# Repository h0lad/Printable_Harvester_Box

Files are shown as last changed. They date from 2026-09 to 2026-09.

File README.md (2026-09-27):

## What is this thing?

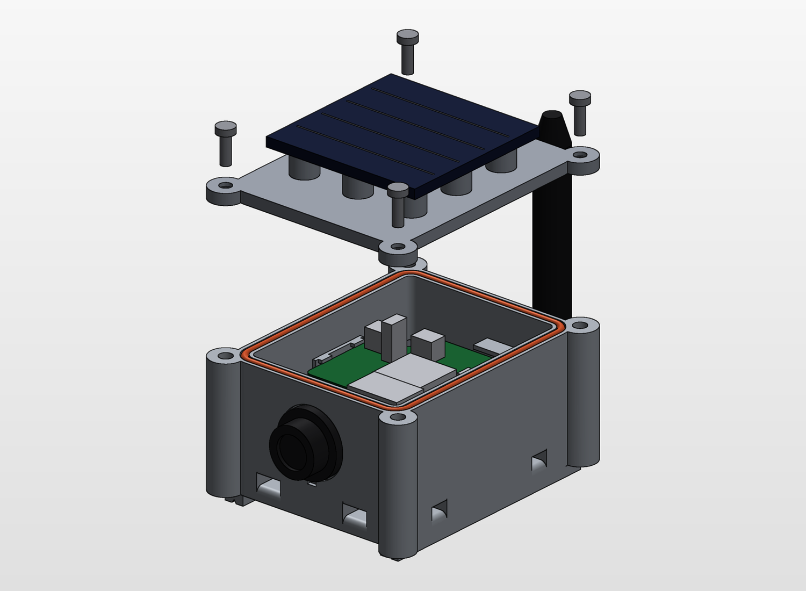
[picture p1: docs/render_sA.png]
An exploded view: the lid and its solar panel lifted off the base, with the O-ring cord and the PCB in place

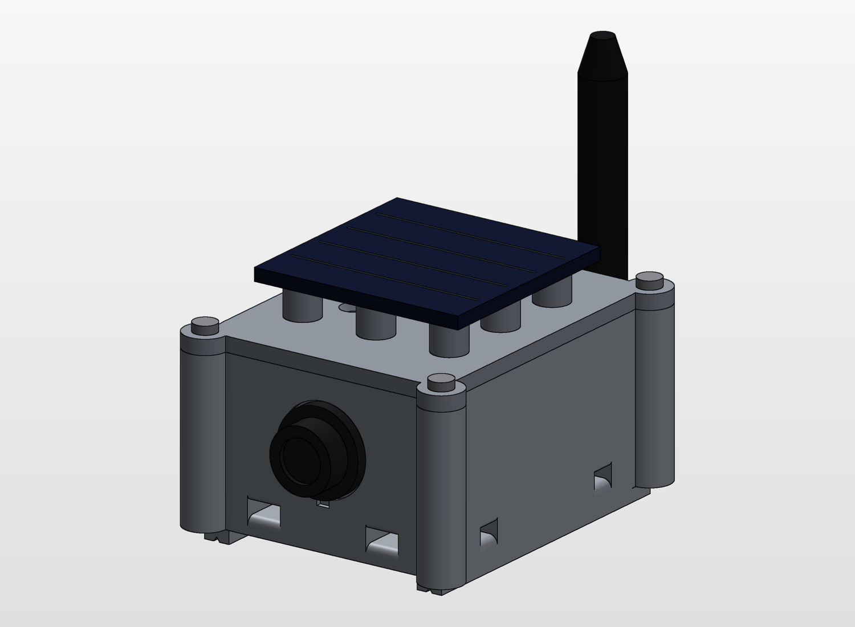
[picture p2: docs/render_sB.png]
The assembled box, with the SMA bulkhead in the front wall and the antenna standing above it

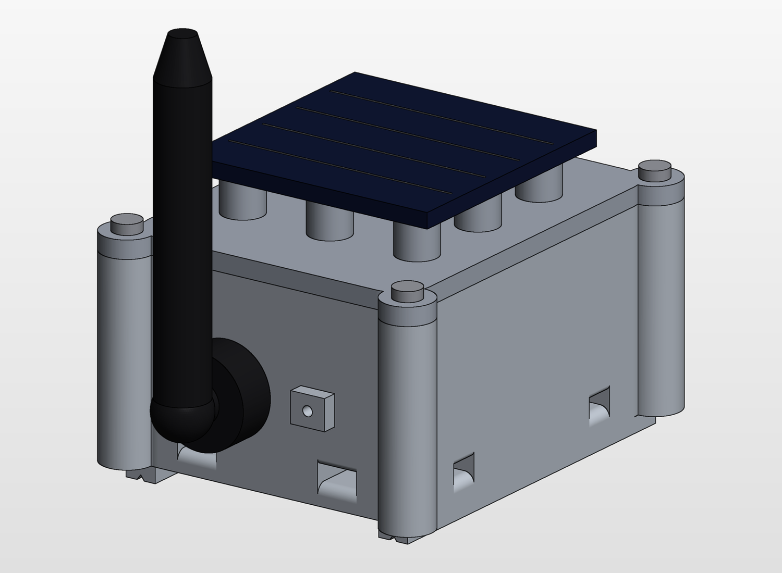
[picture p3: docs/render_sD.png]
The assembled box seen from the antenna corner, with the vent plug in the side wall


This box holds a PicoLoRaHarvester or a LoRaHarvesterbox.

## Dimensions

The body is 73.2 x 58.2 x 41.5 mm. It measures 83 x 68 mm over the screw columns and 44.5 mm over the
skids.

Two skids of 6 x 3 mm run under the floor, and each one carries a 3 x 1 mm V-groove in its face.

The inner cavity is 64 x 49 x 29 mm, and the vent chamber occupies x 56 to 64.

## Material

Bright nylon, printed by SLS or MJF. One material that JLC3DP stocks is 3301PA nylon, printed by SLS.

Don't even think of using PLA...

## Components to buy

- LiPo 852040, up to 45 mm including the protection board, with a JST-PH lead
- SMA bulkhead to U.FL pigtail, inner nose up to 20 mm, with its O-ring and at least 90 mm of cable
- Solar panel, 50 x 50 mm, bonded with epoxy or MS polymer
- ePTFE vent plug, thread 12 mm diameter and 10 mm long, head up to 20 mm, with its plastic nut
- 2 mm silicone O-ring cord, about 250 mm
- 4 M3x8 A4 screws, 1 M2x5 screw, and 4 M3 heat set inserts
- Cable ties of 5 x 1.5 mm, or cord up to 3 mm, for the lashing tunnels

## License

CERN Open Hardware Licence Version 2 - Strongly Reciprocal

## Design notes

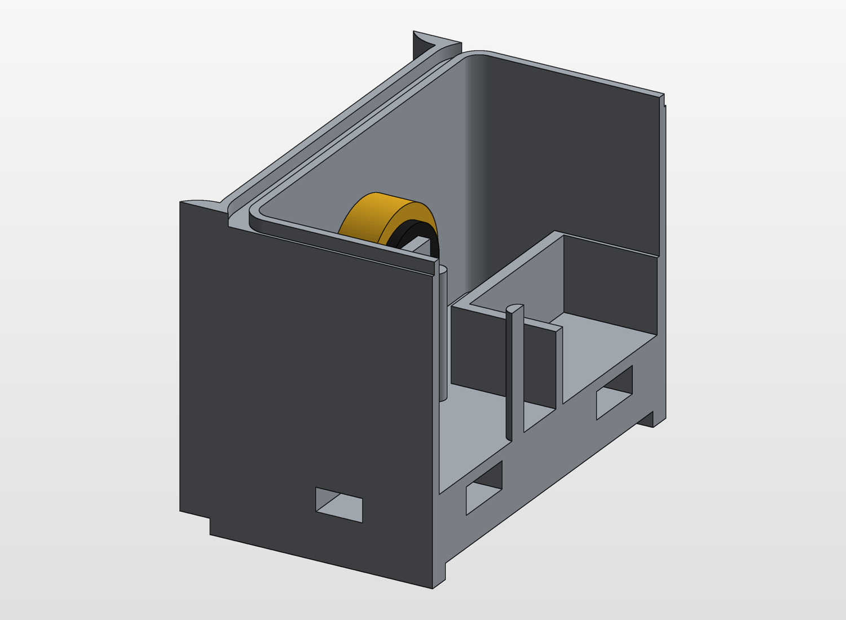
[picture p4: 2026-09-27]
docs/render_sF.png

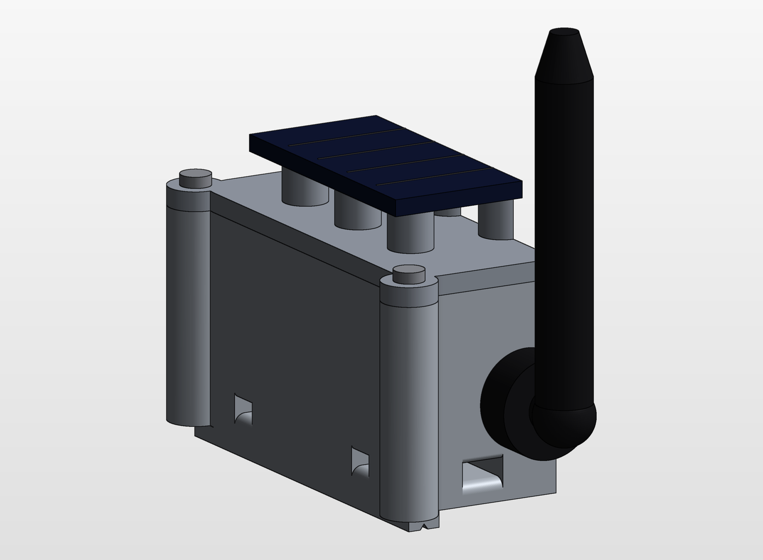
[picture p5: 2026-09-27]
docs/render_sE.png

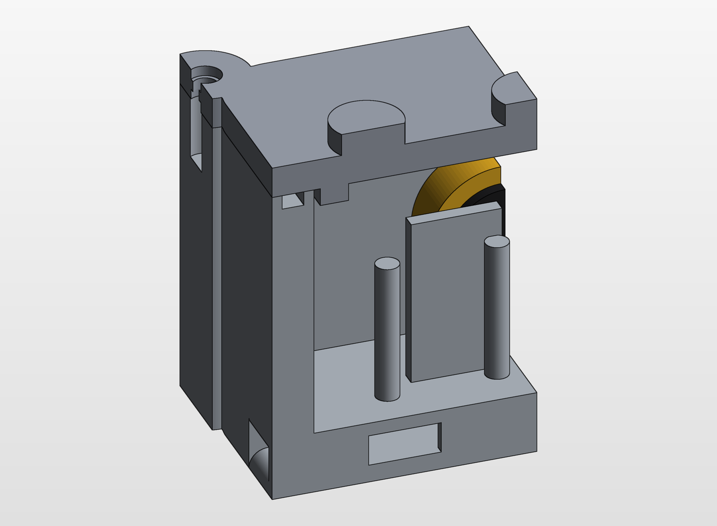
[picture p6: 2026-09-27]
docs/render_sG.png

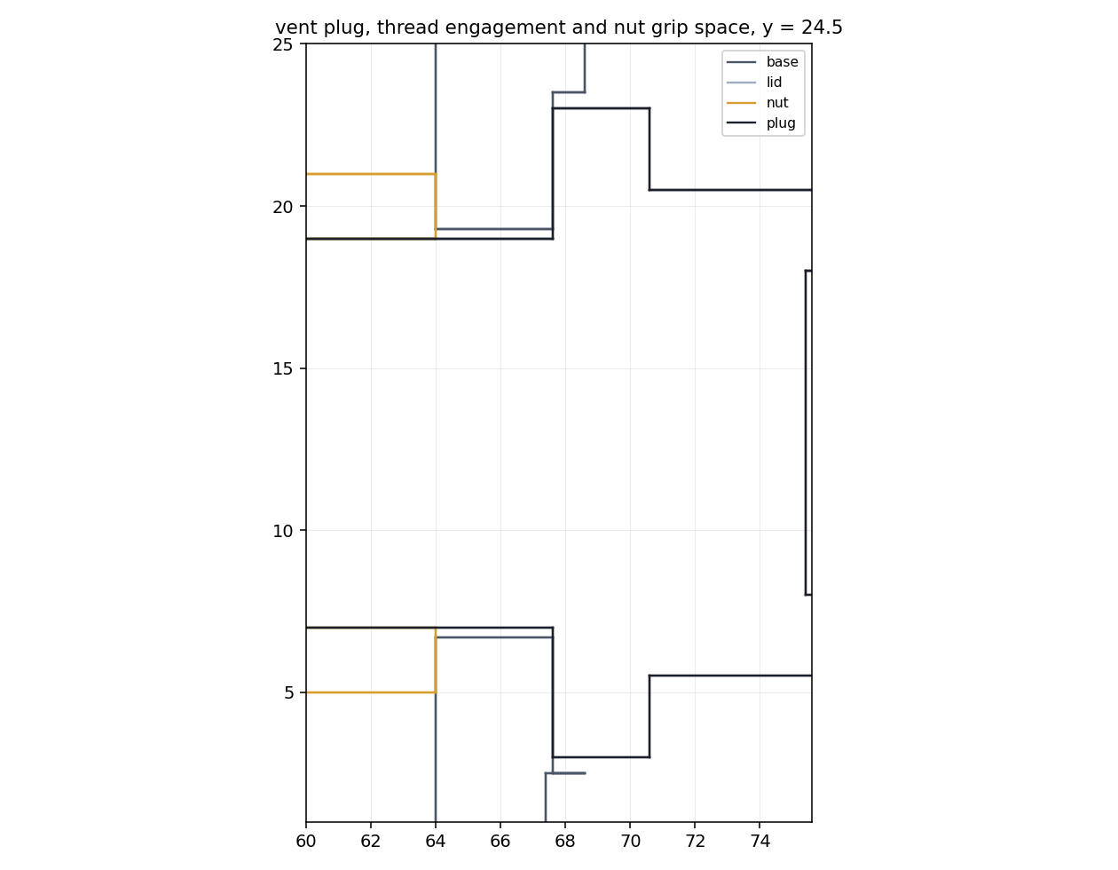
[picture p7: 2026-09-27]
docs/vent_detail.png

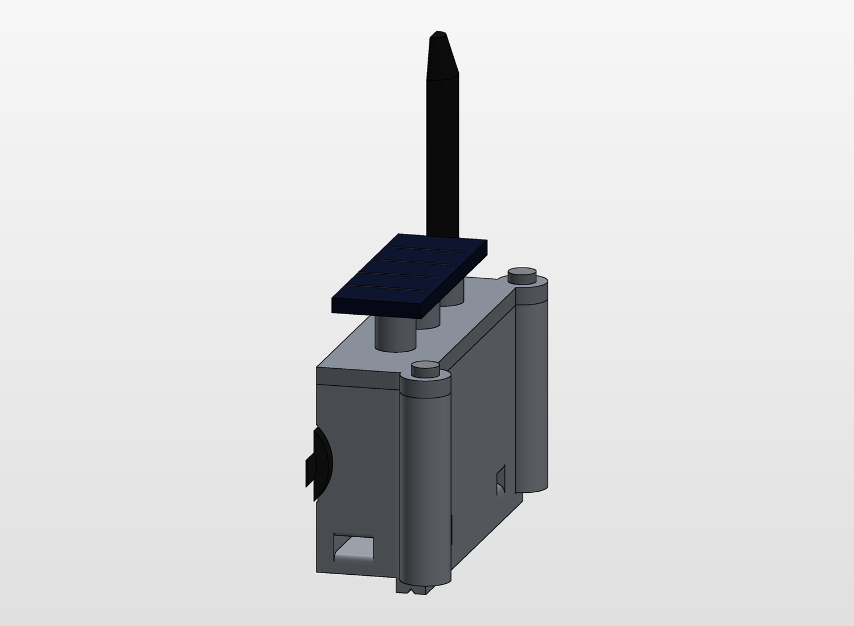
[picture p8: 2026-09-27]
docs/render_sC.png

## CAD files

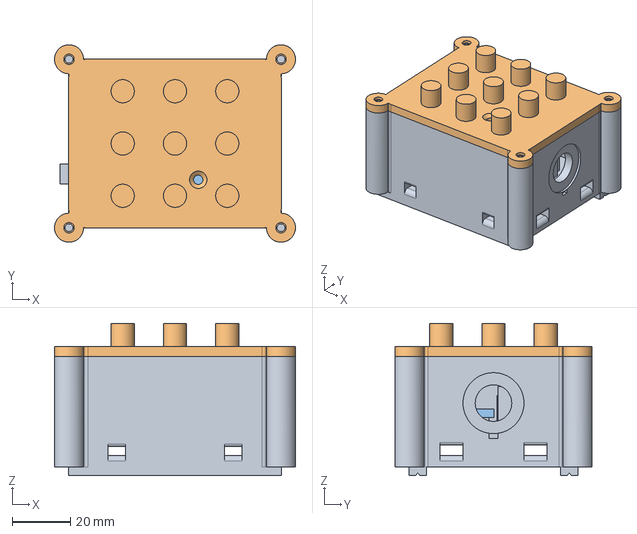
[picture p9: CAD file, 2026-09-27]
steps_stl/LoRaHarvesterBox_assembly.step
83.0 x 68.0 x 52.5 mm

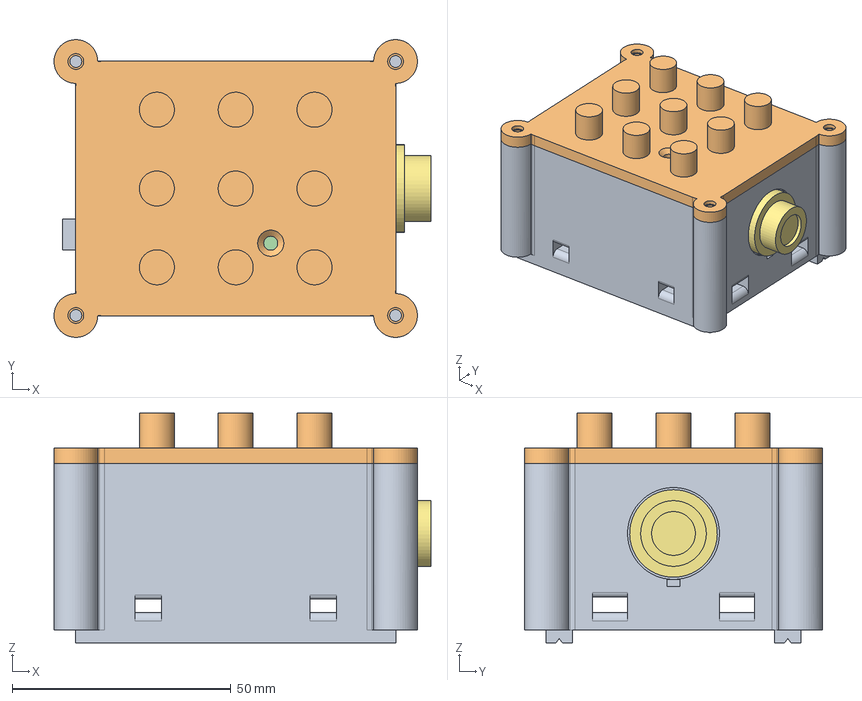
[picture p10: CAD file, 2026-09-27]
freecad/LoRaHarvesterBox_Enclosure.FCStd
86.1 x 68.0 x 52.5 mm
base
lid
battery_plate
PCB_dummy
parts_dummy
LiPo_852040_dummy
vent_plug_dummy
vent_nut_dummy

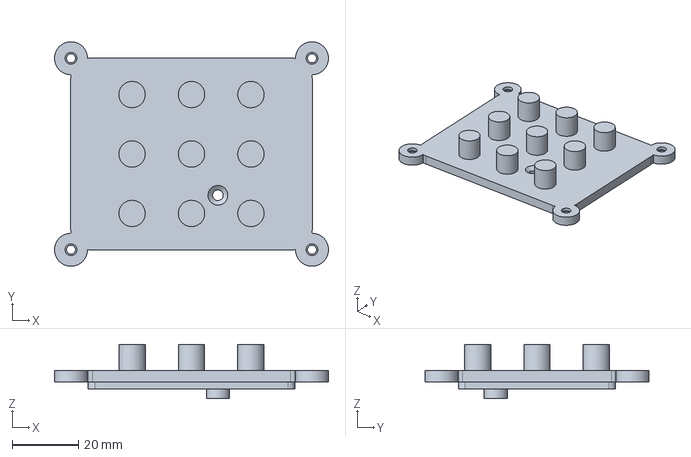
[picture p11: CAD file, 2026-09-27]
steps_stl/LoRaHarvesterBox_lid.step
83.0 x 68.0 x 16.5 mm

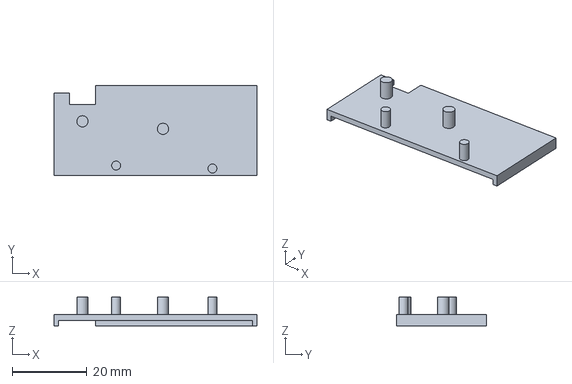
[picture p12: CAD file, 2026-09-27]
steps_stl/LoRaHarvesterBox_battery_plate.step
54.2 x 24.1 x 7.70 mm

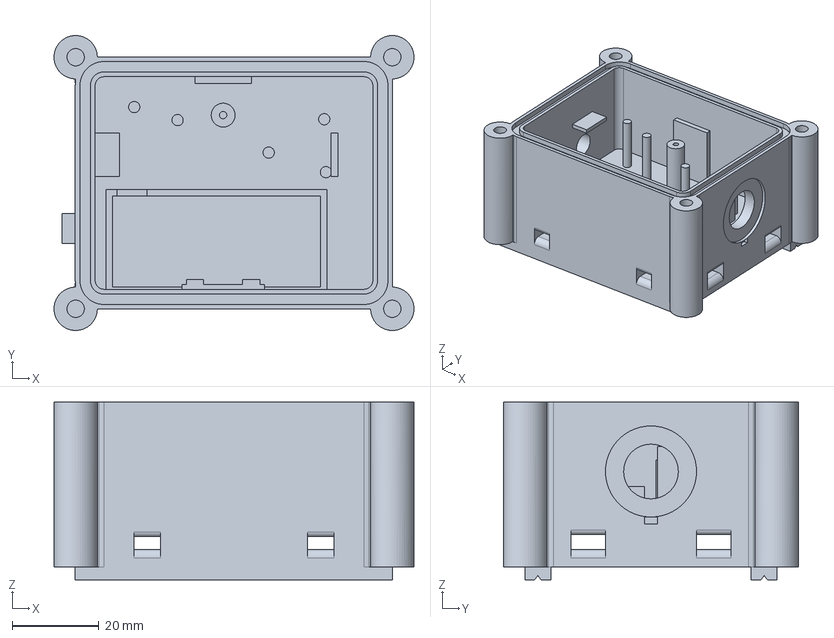
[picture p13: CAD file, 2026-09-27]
steps_stl/LoRaHarvesterBox_base.step
83.0 x 68.0 x 41.0 mm

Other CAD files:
steps_stl/LoRaHarvesterBox_base.stl
steps_stl/LoRaHarvesterBox_battery_plate.stl
steps_stl/LoRaHarvesterBox_lid.stl

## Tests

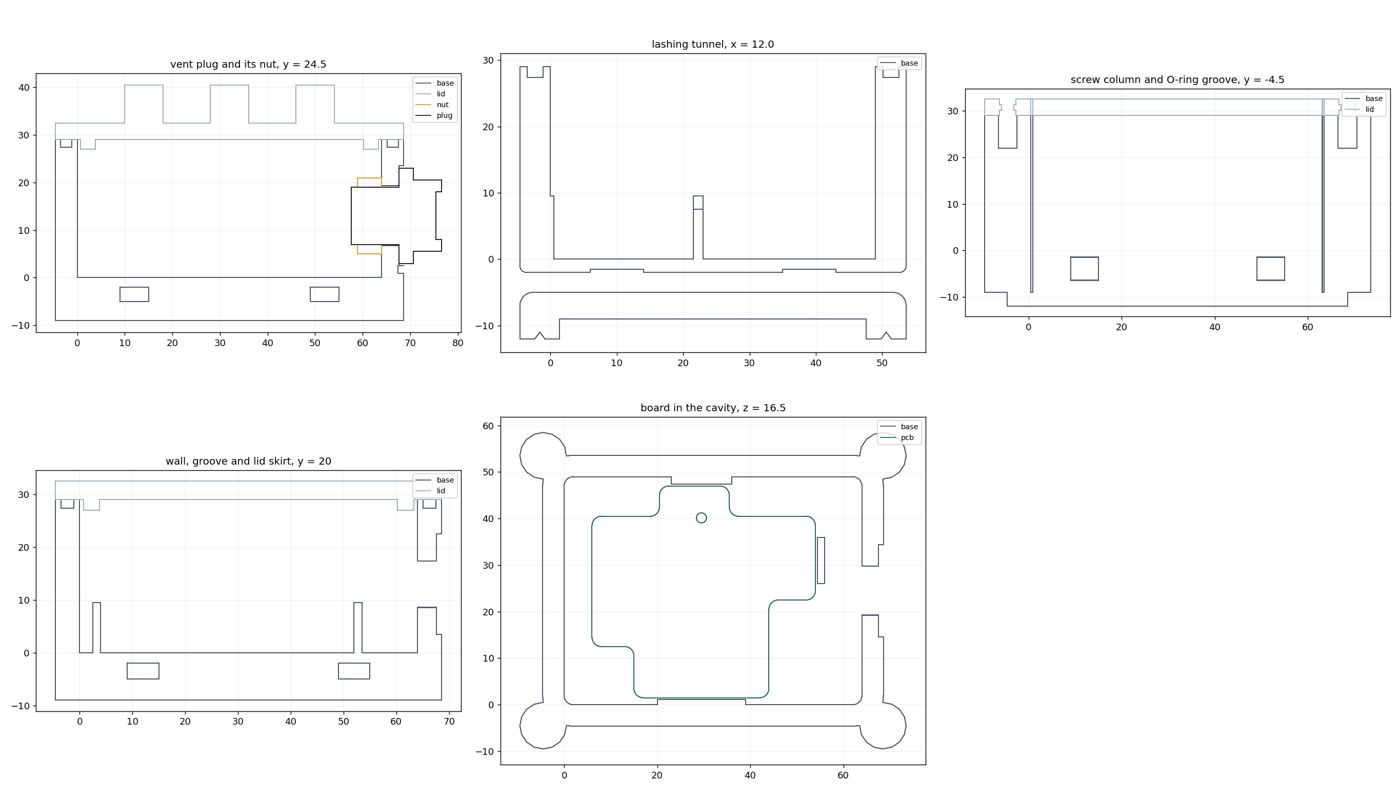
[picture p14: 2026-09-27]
docs/validation_sections.png
